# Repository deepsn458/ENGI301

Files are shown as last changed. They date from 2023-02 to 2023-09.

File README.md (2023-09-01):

# ENGI301
This is a repository for my ENGI301 (Introduction to Practical Electrical Engineering) coursework

The main project is a two-player pattern guesser game made using the Pocket Beagle microprocessor.

[project_01](https://github.com/deepsn458/ENGI301/tree/main/project_01) contains the python code used to run the game

[project_02](https://github.com/deepsn458/ENGI301/tree/main/project_02) contains the schematics and board files for the PCB that was designed for the game

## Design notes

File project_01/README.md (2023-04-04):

# 2 Player Pattern Memory Game

## Introduction
This repository provides the code needed to run the Pattern Memory Game on the PocketBeagle. For more information on the game and setting up the hardware, please visit the [hackster.io](https://www.hackster.io/deepaknarayan458/pattern-guesser-bdb78b) page.

## Dependencies
* Python Package Manager (PIP)
* Adafruit BBIO library
* Adafruit Trellis Library

### Follow the instructions below to install these dependencies
Run the following shell commands in your terminal window
* Update the Linux Advanced Package Tool (apt) and install the Build-Essential package
```sh
  sudo apt-get update
  sudo apt-get install build-essential python-dev python setuptools python-smbus -y
 ```
 * Installing pip
 Install the version compatible with your version of python (version 2.x.x vs version 3.x.x)
 ```sh
 sudo apt-get install python-pip -y
 sudo apt-get install python3-pip -y
 ```
 * Install zip
 ```sh
 sudo apt-get install zip
 ```
* Install the required Adafruit libraries
```sh
sudo pip3 install --upgrade setuptools
sudo pip3 install --upgrade Adafruit_BBIO
sudo pip3 install adafruit-blinka
sudo pip3 install adafruit-circuitpython-trellis
```

## Usage
The game will run when the PocketBeagle is powered on. It can also be run from the Cloud9 IDE with the following commands
```sh
debian@beaglebone:/var/lib/cloud9/ENGI301/project_01/main_game$ ./run
```
### Testing hardware drivers
Navigate to the drivers directory to access the python files for the hardware drivers.
The following command will run the button driver test
```sh
debian@beaglebone:/var/lib/cloud9/ENGI301/project_01/drivers$ python3 nav_button.py
```

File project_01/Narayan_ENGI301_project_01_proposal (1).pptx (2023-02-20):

## ENGI 301 2- Player Pattern Memory Game Proposal

13th February 2023
Deepak Narayan

## Background Information: My Story

- One player sets a pattern using a keypad; the other is briefly shown the pattern and then attempts to replicate it correctly
- Turning the standard memory pattern game into a 2-player game seemed like a good project to get started in learning to make a game
- I am also interested in learning about multiplexing and Charlieplexing. I hope to learn a lot about how LED matrices work through this project.

## Background Information: Overview of the Game

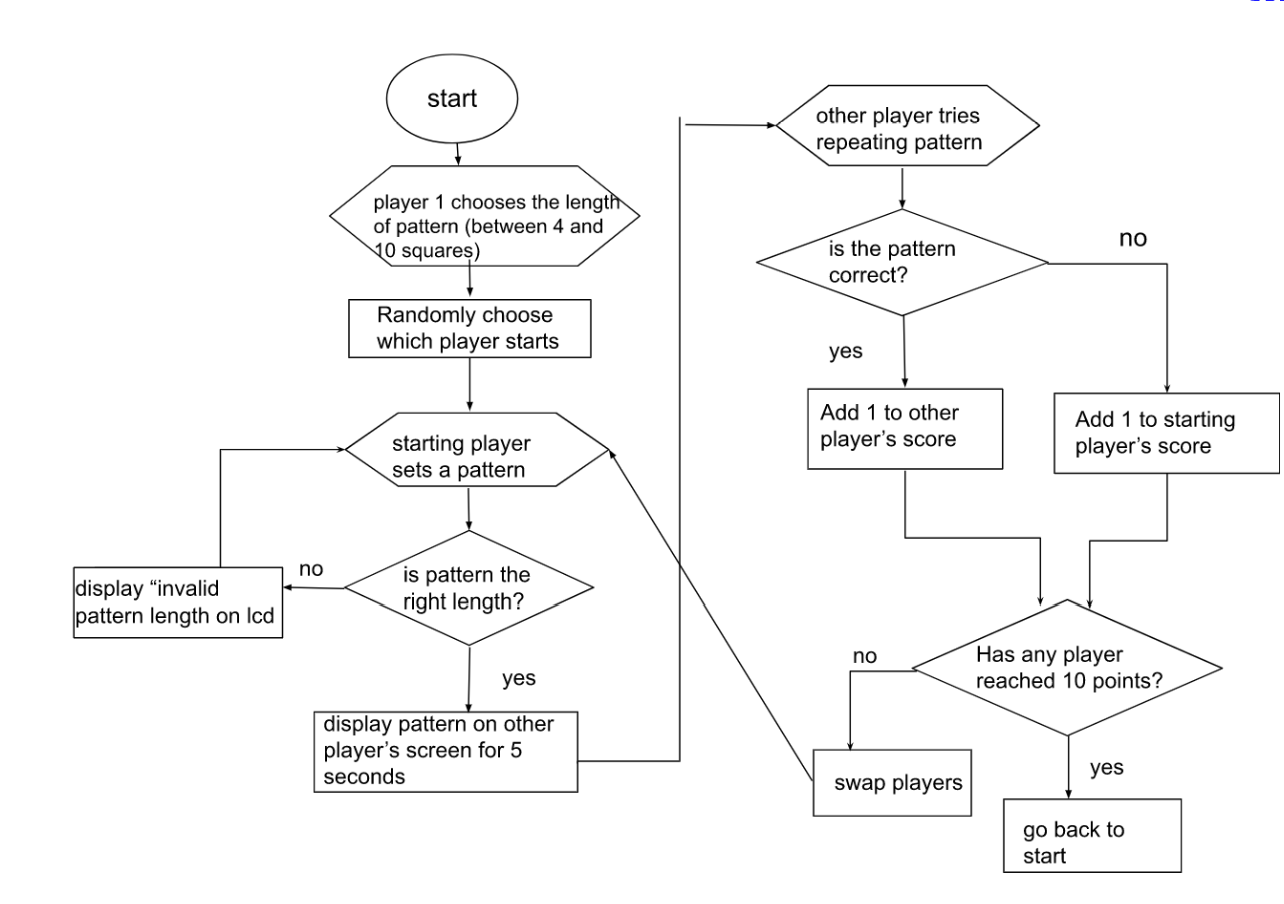
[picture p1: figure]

Figure 1: Game Logic Flowchart

## Background Information: The Device

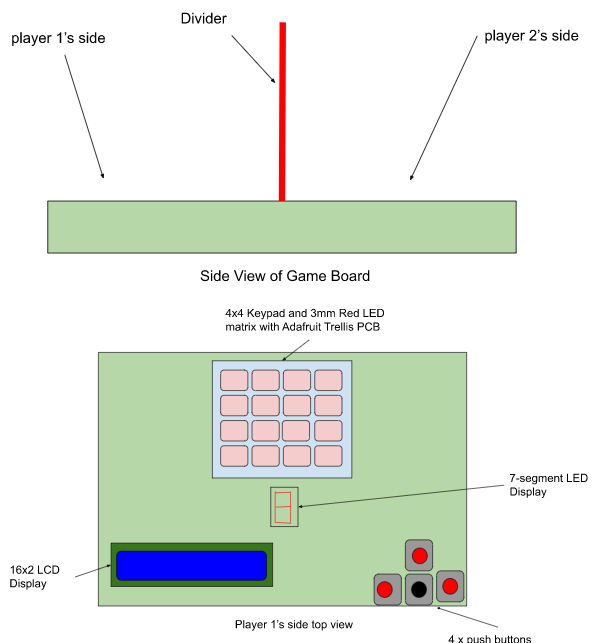
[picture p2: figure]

Figure 2: Side view of game board (top) and top view of Player 1’s side(bottom)

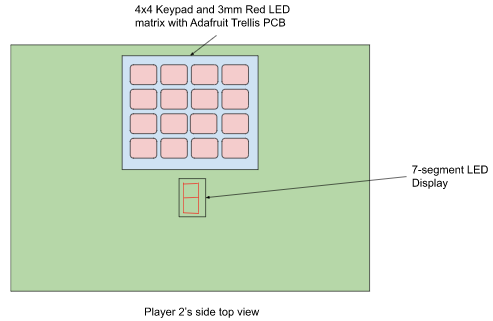
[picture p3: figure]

Figure 3: Top view of player 2’s side

## Background Information: The Device

- Player 1 interfaces with LCD with the pushbuttons to select the pattern length
- Players’ Score is shown on 7-segment LED

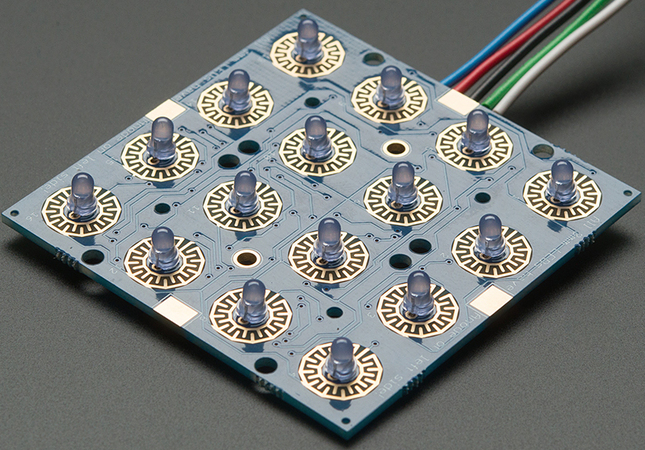
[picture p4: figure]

Figure 4: Adafruit Trellis PCB with LEDs installed (Rembor) [1]

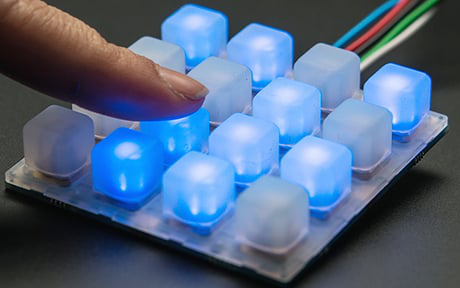
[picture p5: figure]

Figure 5: Adafruit Trellis PCB with LEDs and 4x4 keypad (Rembor) [2]

[1]: Rembor, Kattni “Adding LEDs” Adafruit, 6 Dec. 2013, https://learn.adafruit.com/adafruit-trellis-diy-open-source-led-keypad/adding-leds Accessed 12 Feb. 2023.

[2]: Rembor, Kattni “Overview” Adafruit, 6 Dec. 2013, https://learn.adafruit.com/adafruit-trellis-diy-open-source-led-keypad/overview Accessed 12 Feb. 2023

## Background Information: Existing Project and Improvements

- My project is based on a Pattern Memory Game with the Tessel 1 Development Board:
  - https://www.hackster.io/nmoadev/rebloc-099bdd
  - https://github.com/nmoadev/reBloc/blob/master/rebloc.js
  - My project adds multiplayer and the option to choose the size of the pattern.
    - Additional software: code to store patterns, validate patterns, swap players, and count score
    - Additional hardware: 16x2 LCD display, push buttons, 7-segment LED Display

## System Block Diagram

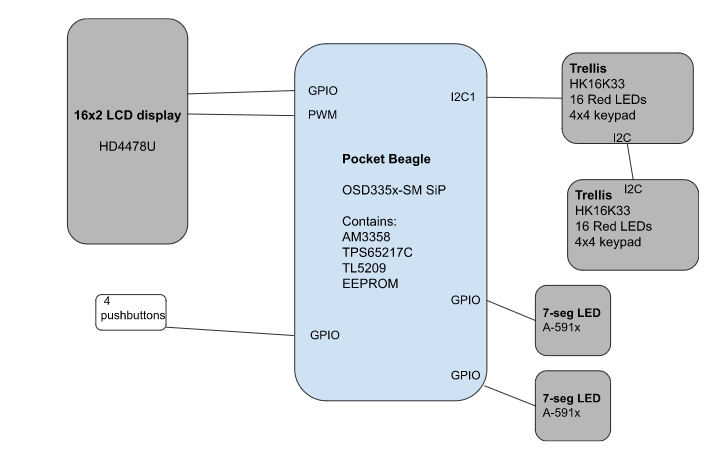
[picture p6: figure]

Figure 5: System block diagram for the game

## Power Block Diagram

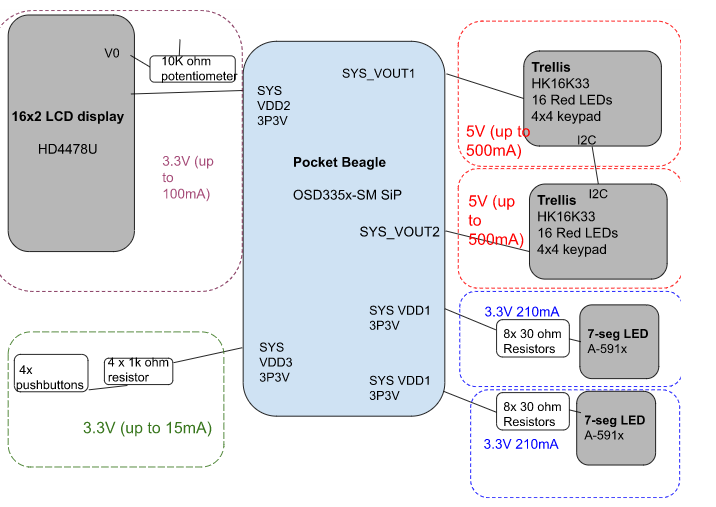
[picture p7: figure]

The datasheet for the Trellis does not specify an exact value for the current draw. An additional power source might be needed.

Figure 6: Power Block Diagram of Game

## Components / Budget

Component | Need to Buy | Total
Adafruit Trellis Driver PCB (https://www.adafruit.com/product/1616) | 2 | $19.90
Trellis Elastomer Keypad (https://www.digikey.com/en/products/detail/adafruit-industries-llc/1611/5823361) | 2 | $9.90
Standard LCD 16x2 + extras (https://www.adafruit.com/product/181https:/www.adafruit.com/product/181) | 1 | $9.95
USB power supply (https://www.amazon.com/SIXTHGU-Portable-Capacity-External-Indicator/dp/B08QHG7BTB) | 1 | $11.89
7-Segment LED Display (https://www.adafruit.com/product/1002) | 1 | $10.95

I can source the 7-seg LEDs, buttons, and Red LEDs myself and from the parts kit

An additional power source may be needed after the current draw of the Trellis is measured

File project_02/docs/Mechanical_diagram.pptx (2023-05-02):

## ENGI 301 PCB Project

Deepak Narayan
Due 05/02/2022 @ 11:59pm

## Options

- Can choose one of two options:
  1. Create a PCB based on your Project #1
  2. Create a PCB based on an example project
- See Project #2 assignment for specific details
  - If choosing Option 1
    - Replace Background Information and System Block Diagram slides with your slides from the Project #1 proposal
    - Create a Mechanical Drawing
  - If choosing Option 2
    - Used provided Background Information and System Block Diagram slides
    - Create a Mechanical Drawing

## Background Information: The Device

- Player 1 interfaces with LCD with the pushbuttons to select the pattern length
- Players’ Score is shown on 7-segment LED


Figure 4: Adafruit Trellis PCB with LEDs installed (Rembor) [1]


Figure 5: Adafruit Trellis PCB with LEDs and 4x4 keypad (Rembor) [2]

[1]: Rembor, Kattni “Adding LEDs” Adafruit, 6 Dec. 2013, https://learn.adafruit.com/adafruit-trellis-diy-open-source-led-keypad/adding-leds Accessed 12 Feb. 2023.

[2]: Rembor, Kattni “Overview” Adafruit, 6 Dec. 2013, https://learn.adafruit.com/adafruit-trellis-diy-open-source-led-keypad/overview Accessed 12 Feb. 2023

## Background Information: Existing Project and Improvements

- My project is based on a Pattern Memory Game with the Tessel 1 Development Board:
  - https://www.hackster.io/nmoadev/rebloc-099bdd
  - https://github.com/nmoadev/reBloc/blob/master/rebloc.js
  - My project adds multiplayer and the option to choose the size of the pattern.
    - Additional software: code to store patterns, validate patterns, swap players, and count score
    - Additional hardware: 16x2 LCD display, push buttons, 7-segment LED Display

## System Block Diagram

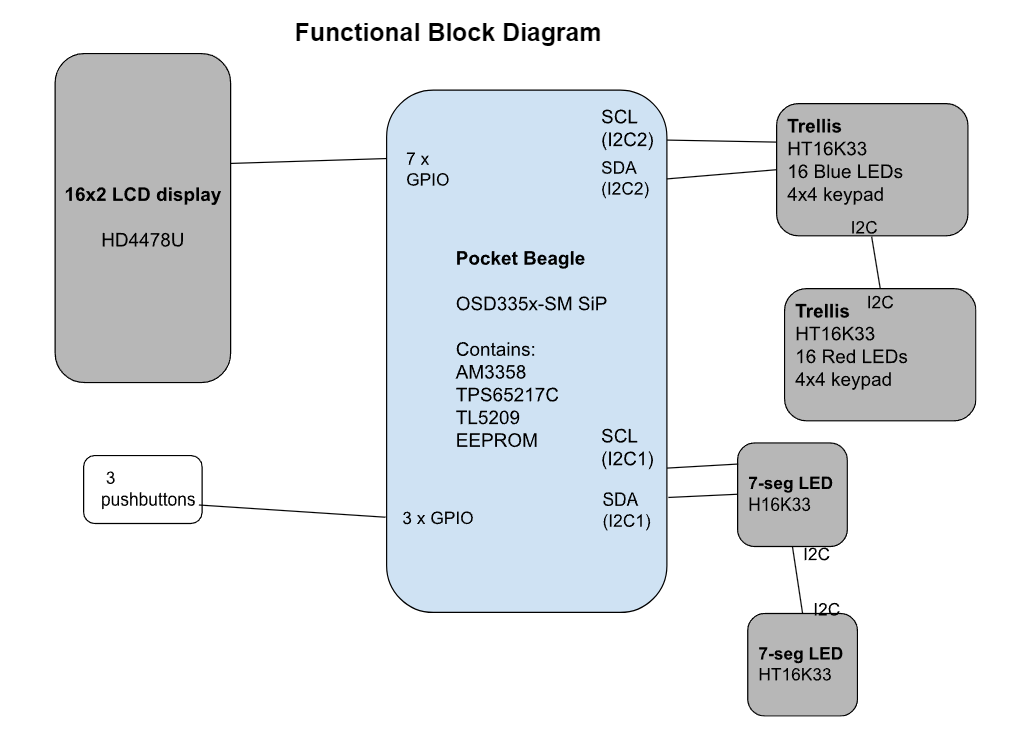
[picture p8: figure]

Figure 5: System block diagram for the game

## Mechanical Drawing

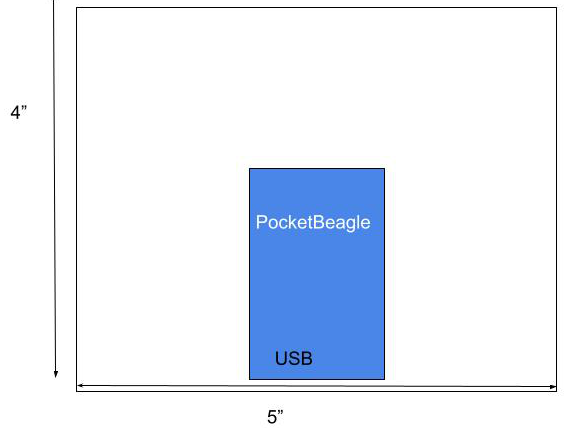
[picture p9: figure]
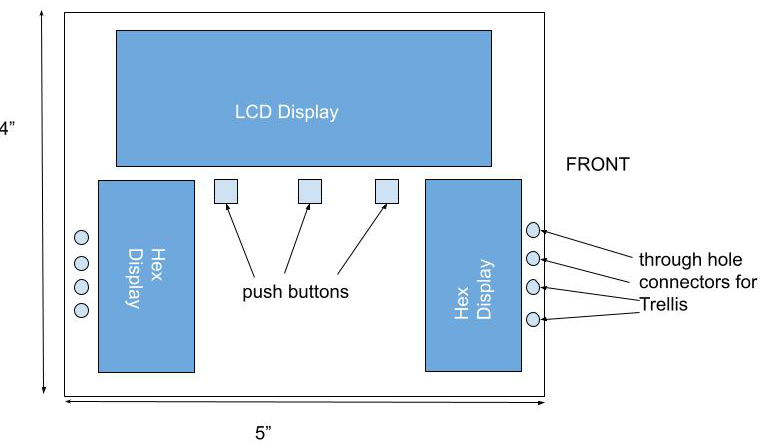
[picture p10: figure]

FRONT

BACK

## Example Mechanical Drawing (from Combo Lock)

Hex Display

3”

.25”

Pocket Beagle

.5”

USB

2”

Button

Pot

Buzzer

Servo

1.5”

FRONT

BACK

Remove this slide in your submission

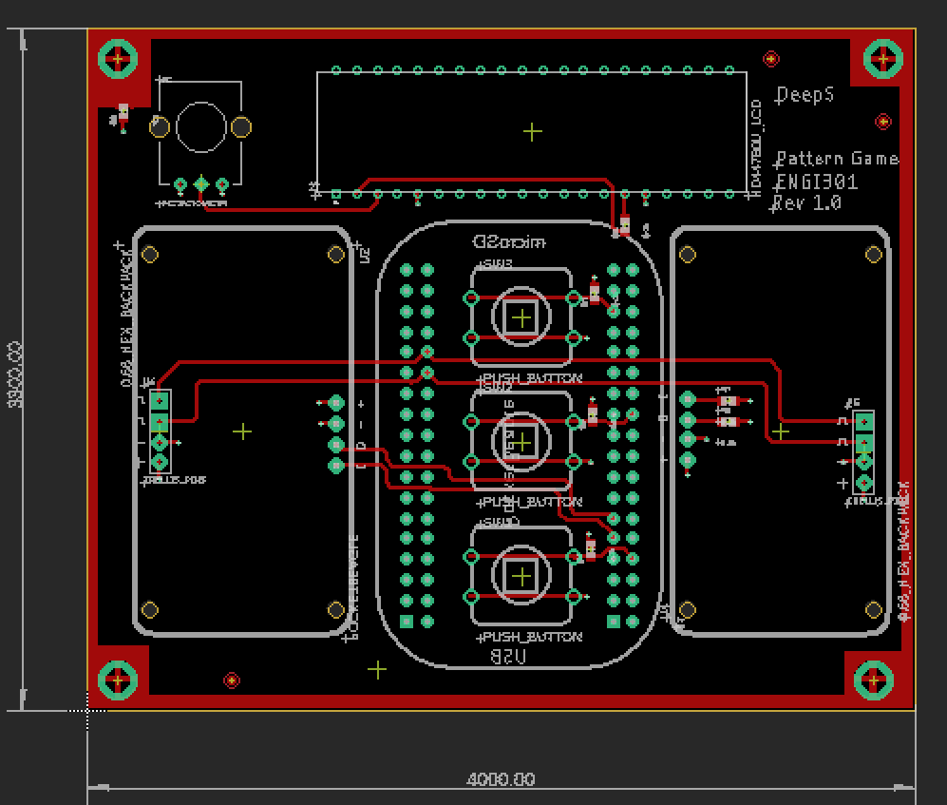
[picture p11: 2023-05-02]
project_02/docs/Top_Layer.png

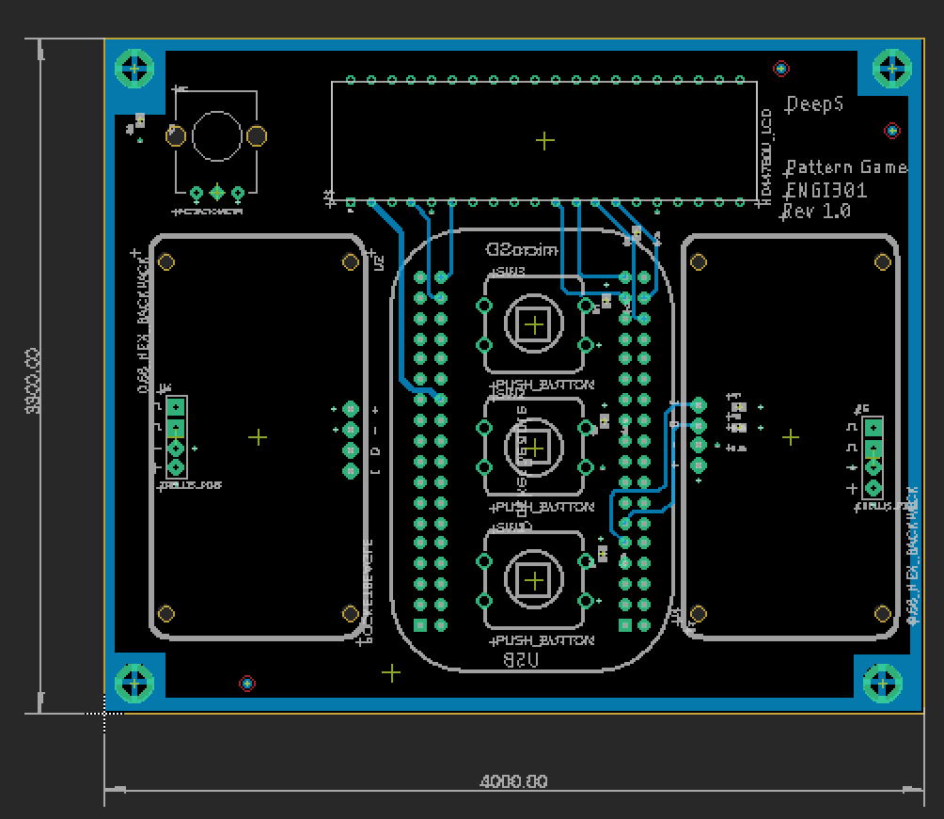
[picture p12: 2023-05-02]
project_02/docs/Bottom_Layer.png

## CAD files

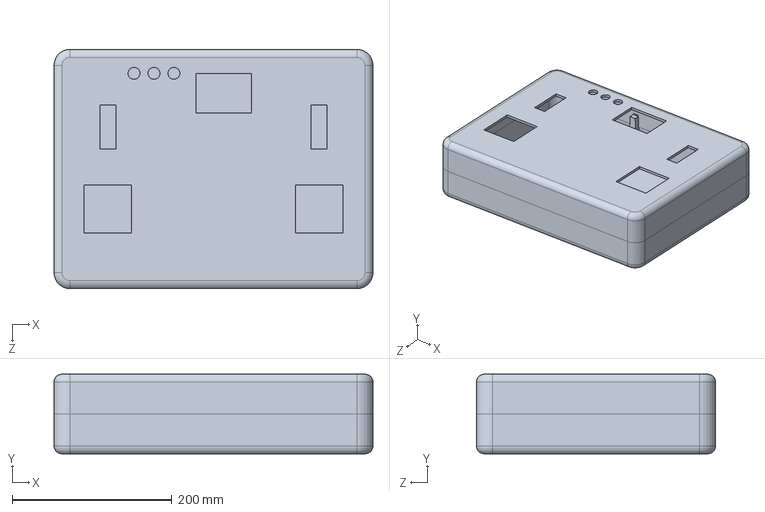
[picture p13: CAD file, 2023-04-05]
enclosure.SLDPRT
400.0 x 100.0 x 300.0 mm

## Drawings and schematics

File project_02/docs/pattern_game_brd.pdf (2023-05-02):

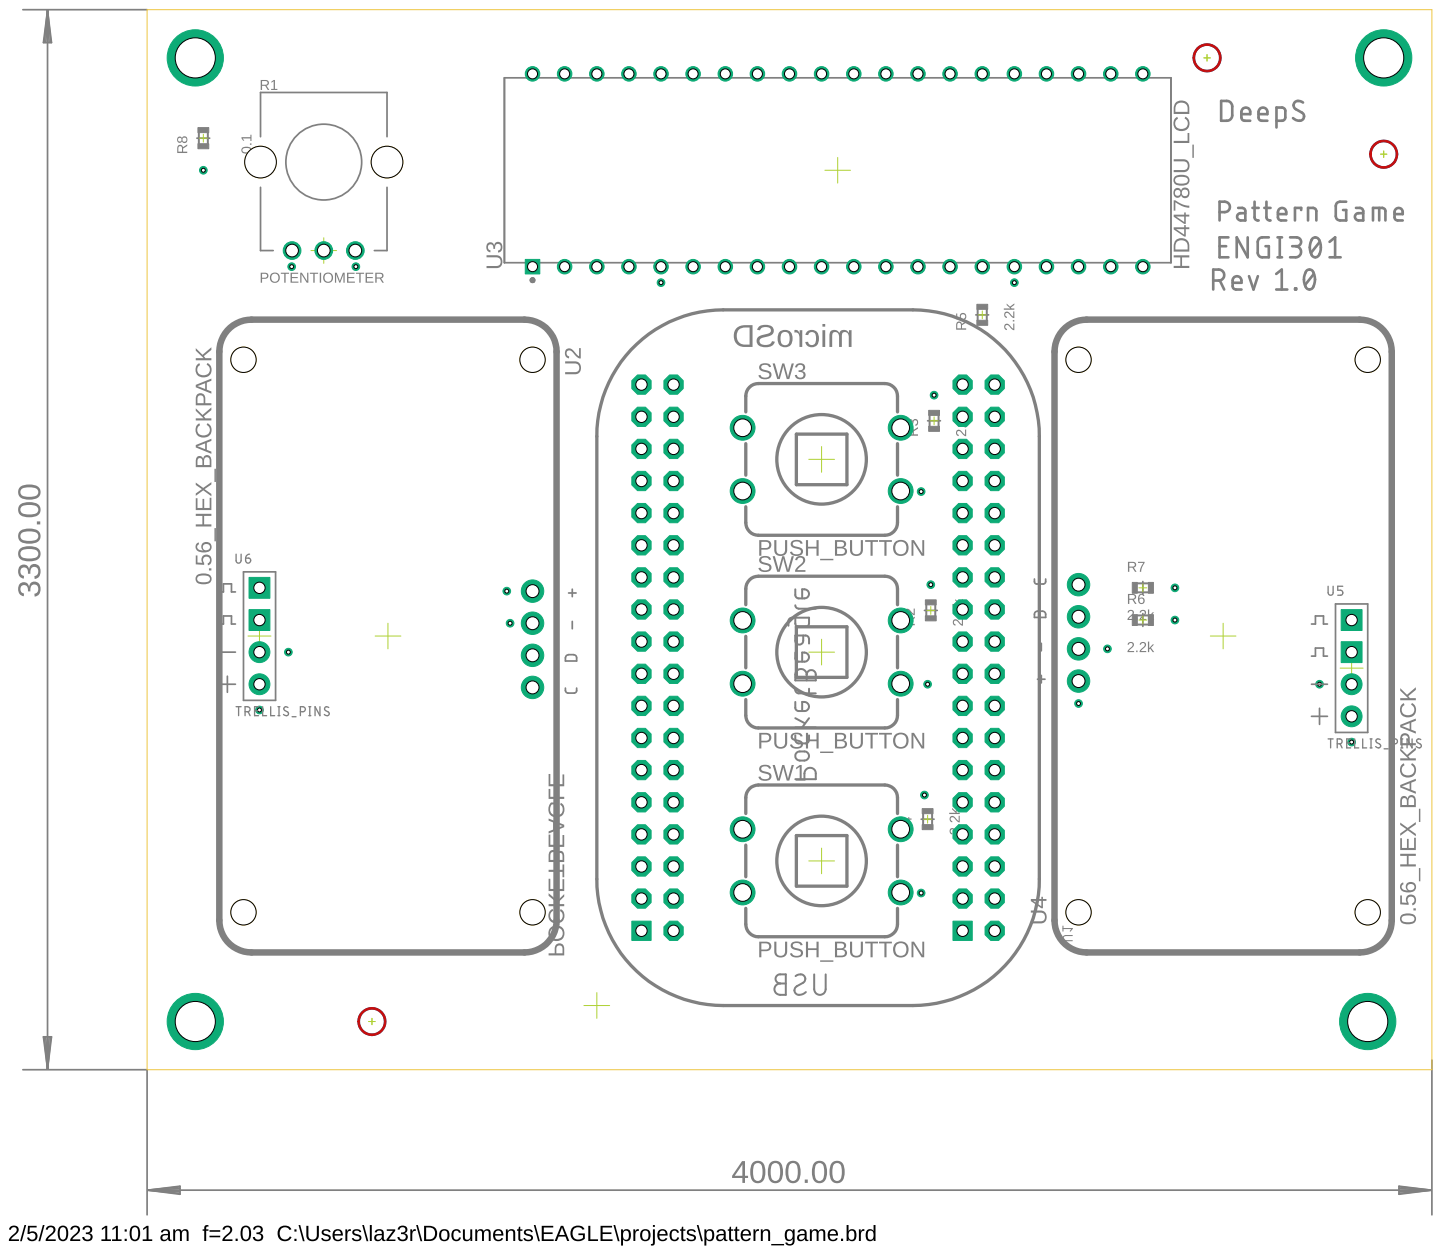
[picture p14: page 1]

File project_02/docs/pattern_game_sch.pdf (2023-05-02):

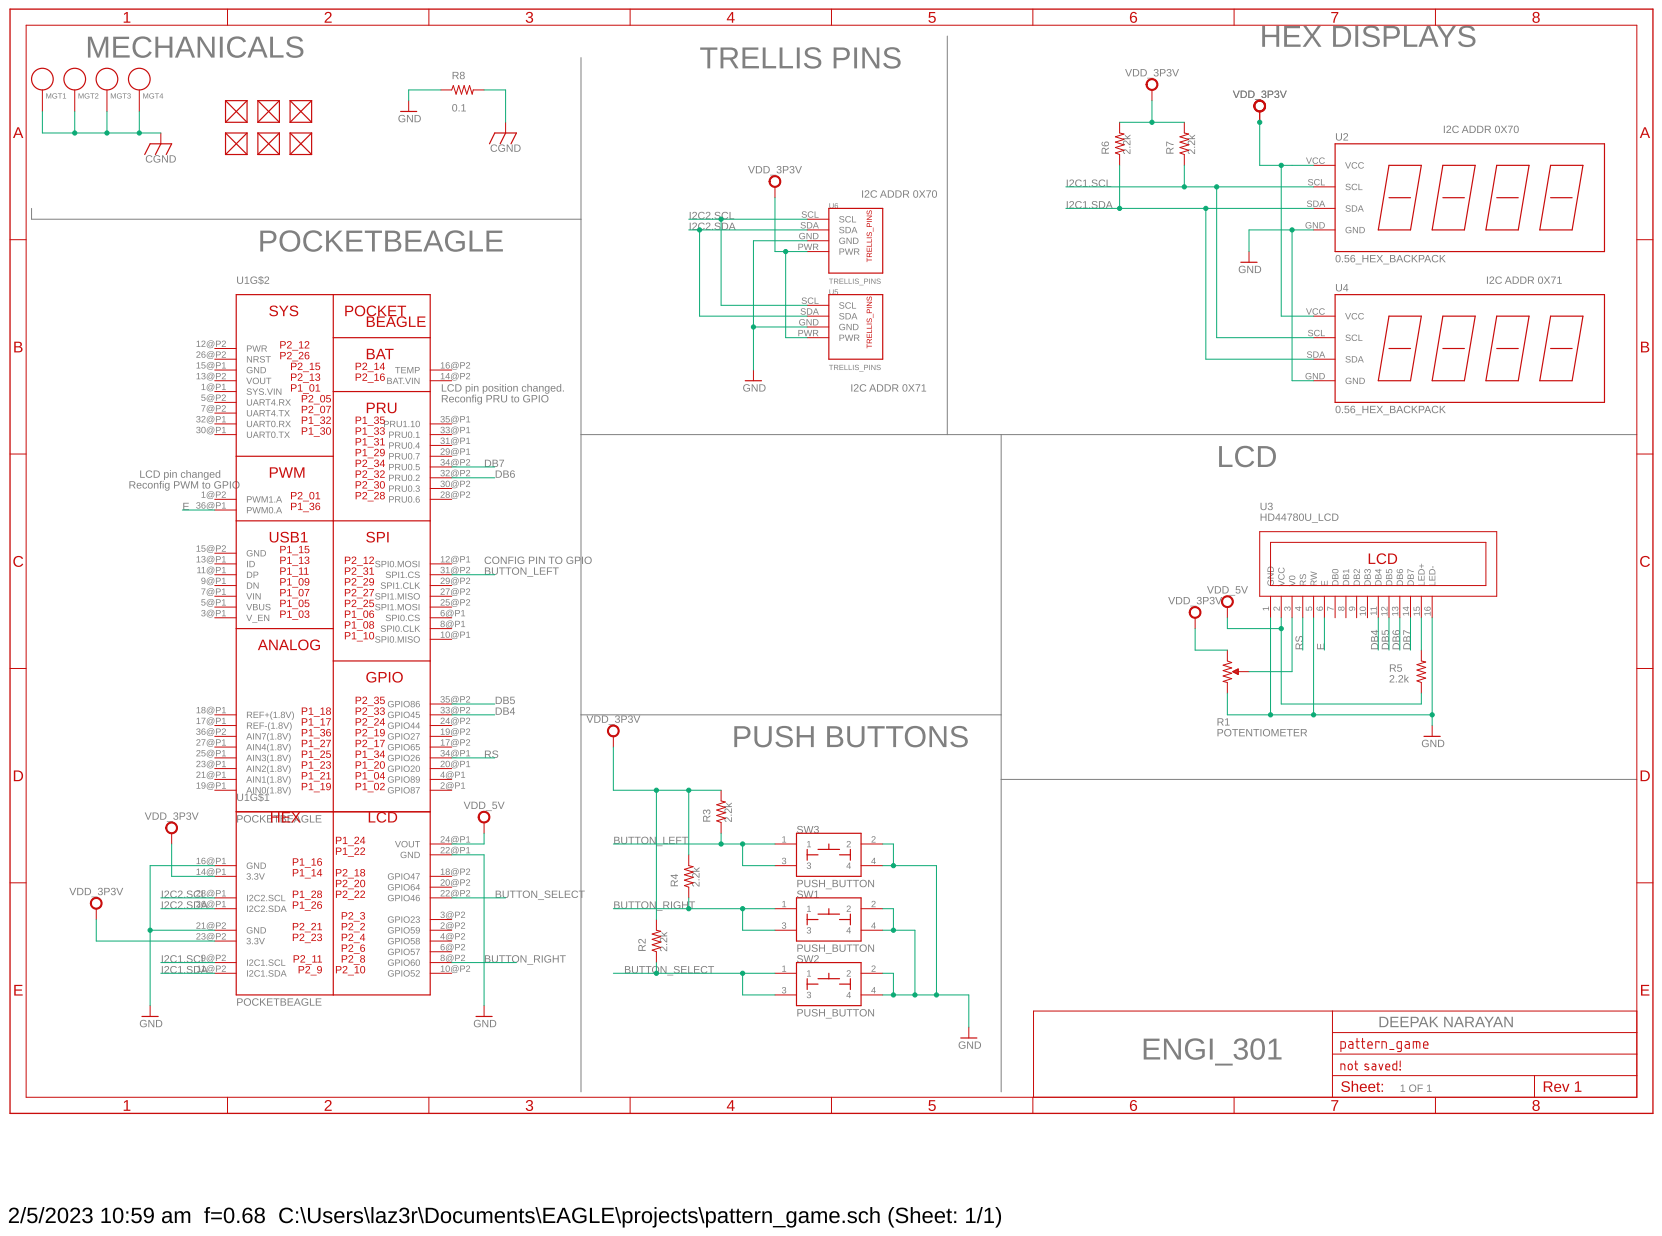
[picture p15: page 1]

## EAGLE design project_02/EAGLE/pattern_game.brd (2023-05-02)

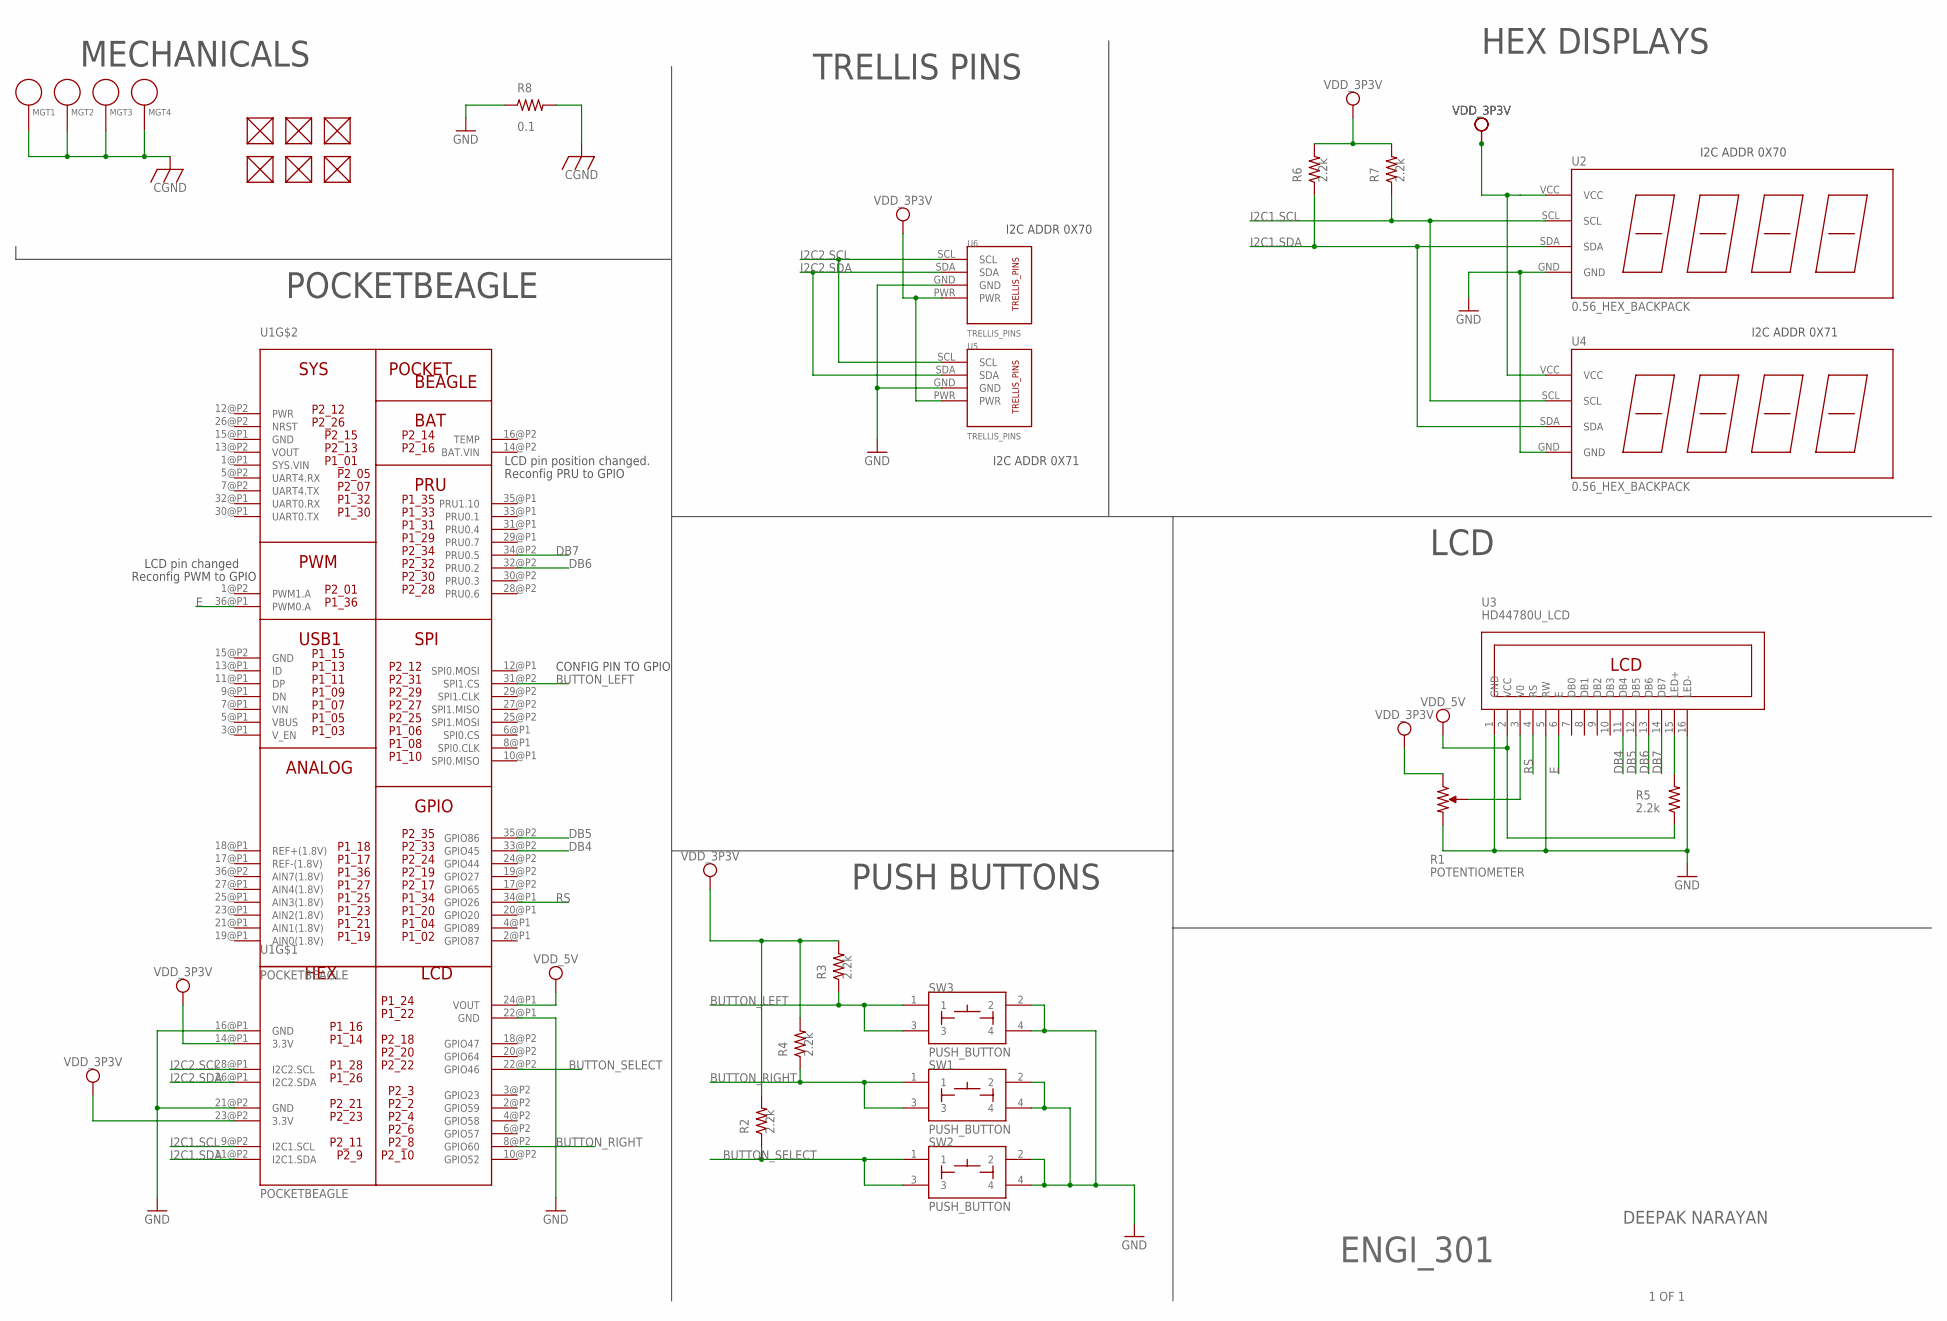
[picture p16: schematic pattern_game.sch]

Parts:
FUD1, FUD2, FUD3, FUD4, FUD5, FUD6: FIDUCIAL; FIDUCIAL_40MIL
MGT1, MGT2, MGT3, MGT4: MOUNTING_HOLE
R1: POTENTIOMETER; POT-PO90S
R2, R3, R4, R5, R6, R7: 2.2k; R0603
R8: 0.1; R0603
SW1, SW2, SW3: PUSH_BUTTON; BUTTON_12.5MM
U1: POCKETBEAGLE
U2, U4: 0.56_HEX_BACKPACK
U3: HD44780U_LCD
U5, U6: TRELLIS_PINS

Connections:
BUTTON_LEFT: R3.1, SW3.1, SW3.3, U1.31@P2 (SPI1.CS)
BUTTON_RIGHT: R4.1, SW1.1, SW1.3, U1.8@P2 (GPIO60)
BUTTON_SELECT: R2.1, SW2.1, SW2.3, U1.22@P2 (GPIO46)
CGND: MGT1.P$1, MGT2.P$1, MGT3.P$1, MGT4.P$1, R8.2
DB4: U1.33@P2 (GPIO45), U3.11 (DB4)
DB5: U1.35@P2 (GPIO86), U3.12 (DB5)
DB6: U1.32@P2 (PRU0.2), U3.13 (DB6)
DB7: U1.34@P2 (PRU0.5), U3.14 (DB7)
E: U1.36@P1 (PWM0.A), U3.6 (E)
GND: R1.CW, R8.1, SW1.2, SW1.4, SW2.2, SW2.4, SW3.2, SW3.4, U1.16@P1 (GND), U1.21@P2 (GND), U1.22@P1 (GND), U2.GND, U3.1 (GND), U3.5 (RW), U3.16 (LED-), U4.GND, U5.GND, U6.GND
I2C1.SCL: R7.1, U1.9@P2 (I2C1.SCL), U2.SCL, U4.SCL
I2C1.SDA: R6.1, U1.11@P2 (I2C1.SDA), U2.SDA, U4.SDA
I2C2.SCL: U1.28@P1 (I2C2.SCL), U5.SCL, U6.SCL
I2C2.SDA: U1.26@P1 (I2C2.SDA), U5.SDA, U6.SDA
unnamed: R1.S, U3.3 (V0)
unnamed: R5.2, U3.15 (LED+)
RS: U1.34@P1 (GPIO26), U3.4 (RS)
VDD_3P3V: R1.CCW, R2.2, R3.2, R4.2, R6.2, R7.2, U1.14@P1 (3.3V), U1.23@P2 (3.3V), U2.VCC, U4.VCC, U5.PWR, U6.PWR
VDD_5V: R5.1, U1.24@P1 (VOUT), U3.2 (VCC)

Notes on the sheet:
LCD
HEX DISPLAYS
I2C ADDR 0X70
I2C ADDR 0X71
TRELLIS PINS
POCKETBEAGLE
PUSH BUTTONS
MECHANICALS
ENGI_301
DEEPAK NARAYAN
1 OF 1
LCD pin position changed.
Reconfig PRU to GPIO
LCD pin changed
Reconfig PWM to GPIO
CONFIG PIN TO GPIO

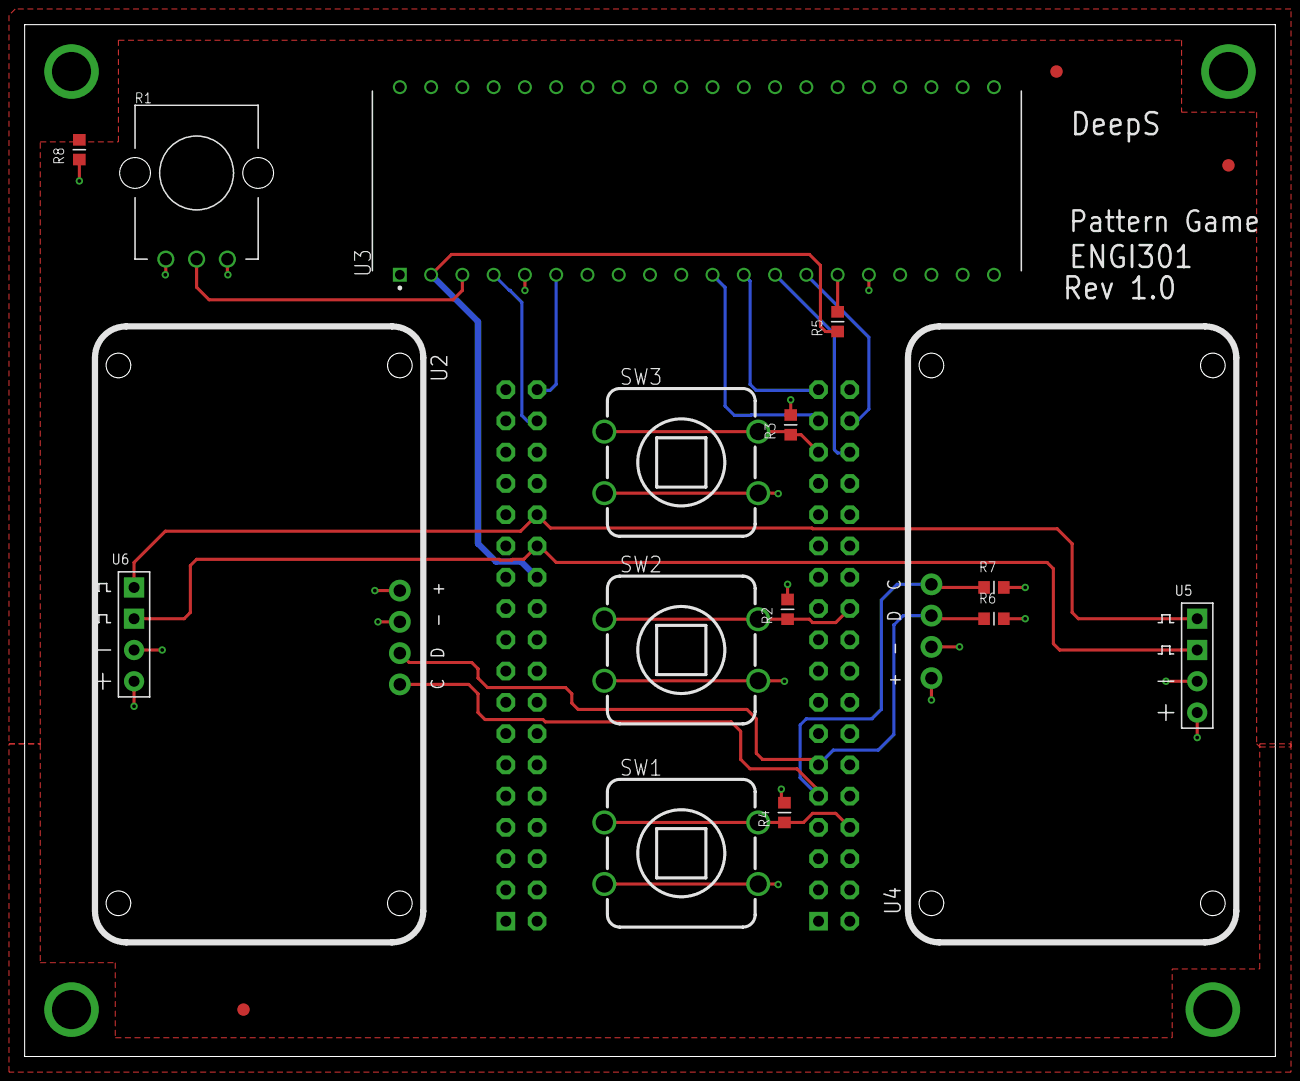
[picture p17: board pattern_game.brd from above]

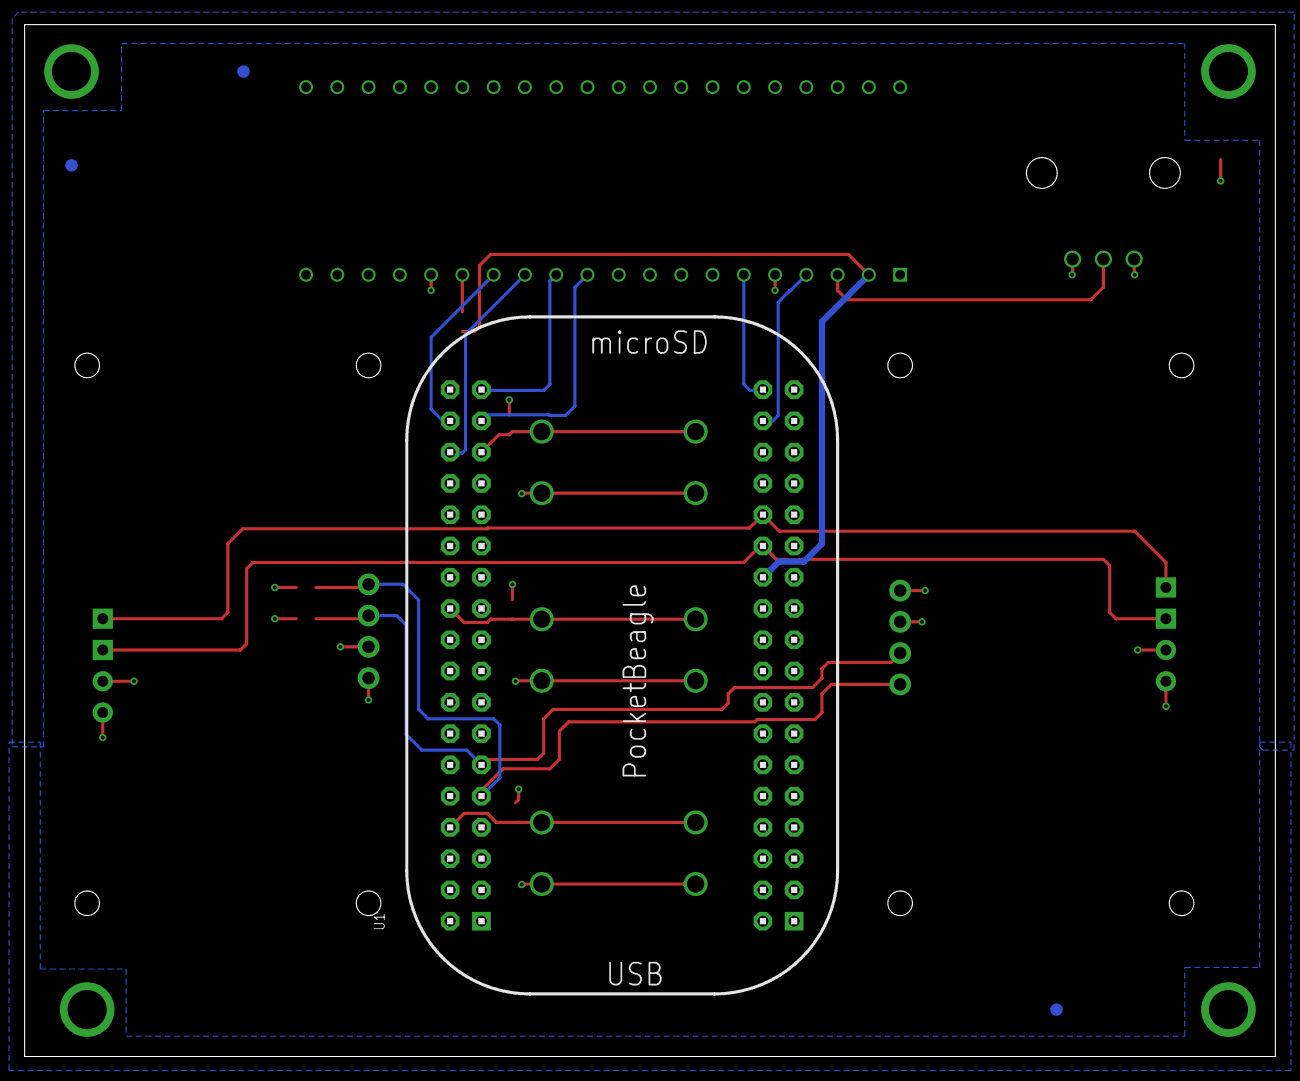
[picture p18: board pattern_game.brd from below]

Board: 4 copper layers, 101.6 x 83.8 mm, 27 parts (4 on the bottom side), 19 nets.

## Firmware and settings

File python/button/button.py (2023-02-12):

"""
--------------------------------------------------------------------------
Button Driver
--------------------------------------------------------------------------
License:   
Copyright 2021-2023 - Erik Welsh

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
1. Redistributions of source code must retain the above copyright notice, this 
list of conditions and the following disclaimer.

2. Redistributions in binary form must reproduce the above copyright notice, 
this list of conditions and the following disclaimer in the documentation 
and/or other materials provided with the distribution.

3. Neither the name of the copyright holder nor the names of its contributors 
may be used to endorse or promote products derived from this software without 
specific prior written permission.

THIS SOFTWARE IS PROVIDED BY THE COPYRIGHT HOLDERS AND CONTRIBUTORS "AS IS" 
AND ANY EXPRESS OR IMPLIED WARRANTIES, INCLUDING, BUT NOT LIMITED TO, THE 
IMPLIED WARRANTIES OF MERCHANTABILITY AND FITNESS FOR A PARTICULAR PURPOSE ARE 
DISCLAIMED. IN NO EVENT SHALL THE COPYRIGHT HOLDER OR CONTRIBUTORS BE LIABLE 
FOR ANY DIRECT, INDIRECT, INCIDENTAL, SPECIAL, EXEMPLARY, OR CONSEQUENTIAL 
DAMAGES (INCLUDING, BUT NOT LIMITED TO, PROCUREMENT OF SUBSTITUTE GOODS OR 
SERVICES; LOSS OF USE, DATA, OR PROFITS; OR BUSINESS INTERRUPTION) HOWEVER 
CAUSED AND ON ANY THEORY OF LIABILITY, WHETHER IN CONTRACT, STRICT LIABILITY, 
OR TORT (INCLUDING NEGLIGENCE OR OTHERWISE) ARISING IN ANY WAY OUT OF THE USE 
OF THIS SOFTWARE, EVEN IF ADVISED OF THE POSSIBILITY OF SUCH DAMAGE.
--------------------------------------------------------------------------

Button Driver

  This driver is built for buttons that have a pull up resistor between the
button and the processor pin (i.e. the input is "High"/"1" when the button is
not pressed) and will be connected to ground when the button is pressed (i.e. 
the input is "Low" / "0" when the button is pressed)

Software API:

  Button(pin)
    - Provide pin that the button monitors
    
    is_pressed()
      - Return a boolean value (i.e. True/False) on if button is pressed
      - Function consumes no time
    
    wait_for_press(function=None)
      - Wait for the button to be pressed 
      - Optionally takes in an argument "function" which is the function 
        to be executed when waiting for the button to be pressed
      - Function consumes time
      - Returns a tuple:  
        (<time button was pressed>, <data returned by the "function" argument>)

"""
import time

import Adafruit_BBIO.GPIO as GPIO

# ------------------------------------------------------------------------
# Constants
# ------------------------------------------------------------------------

# None

# ------------------------------------------------------------------------
# Global variables
# ------------------------------------------------------------------------

# None

# ------------------------------------------------------------------------
# Functions / Classes
# ------------------------------------------------------------------------

class Button():
    """ Button Class """
    pin             = None
    unpressed_value = None
    pressed_value   = None
    sleep_time      = None
    
    def __init__(self, pin=None):
        """ Initialize variables and set up the button """
        if (pin == None):
            raise ValueError("Pin not provided for Button()")
        else:
            self.pin = pin
        
        # By default the unpressed_value is "1" and the pressed
        # value is "0".  This is done to make it easier to change
        # in the future
        self.unpressed_value = 1
        self.pressed_value   = 0
        
        # By default sleep time is "0.1" seconds
        self.sleep_time      = 0.1

        # Initialize the hardware components        
        self._setup()
    
    # End def
    
    
    def _setup(self):
        """ Setup the hardware components. """
        # Initialize Button
        # HW#4 TODO: (one line of code)
        #   Remove "pass" and use the Adafruit_BBIO.GPIO library to set up the button
        GPIO.setup(self.pin, GPIO.IN)
        return
    # End def


    def is_pressed(self):
        """ Is the Button pressed?
        
           Returns:  True  - Button is pressed
                     False - Button is not pressed
        """
        # HW#4 TODO: (one line of code)
        #   Remove "pass" and return the comparison of input value of the GPIO pin of 
        #   the buton (i.e. self.pin) to the "pressed value" of the class 
        print(GPIO.input(self.pin))
        return (GPIO.input(self.pin) == self.pressed_value)

    # End def


    def wait_for_press(self, function=None):
        """ Wait for the button to be pressed.  This function will 
           wait for the button to be pressed and released so there
           are no race conditions.
        
           Arguments:
               function - Optional argument that is the functon to 
                          executed while waiting for the button to 
                          be pressed
        
           Returns:
               tuple - [0] Time button was pressed
                     - [1] Data returned by the "function" argument
        """
        function_return_value = None
        button_press_time     = None
        
        # Execute function if it is not None
        #   - This covers the case that the button is pressed prior 
        #     to entering this function
        if function is not None:
            function_return_value = function()
        
        # Wait for button press
        #   If the function is not None, execute the function
        #   Sleep for a short amount of time to reduce the CPU load
        #
        # HW#4 TODO: (one line of code)
        #   Update while loop condition to compare the input value of the  
        #   GPIO pin of the buton (i.e. self.pin) to the "unpressed value" 
        #   of the class (i.e. we are executing the while loop while the 
        #   button is not being pressed)
        while(GPIO.input(self.pin) == self.unpressed_value):
            if function is not None:
                function_return_value = function()
                
            time.sleep(self.sleep_time)
        
        # Record time
        button_press_time = time.time()
        
        # Wait for button release
        #   Sleep for a short amount of time to reduce the CPU load
        #
        # HW#4 TODO: (one line of code)
        #   Update while loop condition to compare the input value of the  
        #   GPIO pin of the buton (i.e. self.pin) to the "pressed value" 
        #   of the class (i.e. we are executing the while loop while the 
        #   button is being pressed)
        while(GPIO.input(self.pin) == self.pressed_value):
            time.sleep(self.sleep_time)
        
        # Compute the button_press_time
        button_press_time = time.time() - button_press_time

        # Return a tuple:  (button press time, function return value)        
        return (button_press_time, function_return_value)
        
    # End def

# End class



# ------------------------------------------------------------------------
# Main script
# ------------------------------------------------------------------------

if __name__ == '__main__':

    print("Button Test")

    # Create instantiation of the button
    button = Button("P2_2")
    
    # Create an function to test the wait_for_press function
    def print_time():
        ret_val = time.time()
        print("    Print Time = {0}".format(ret_val))
        return ret_val
    # End def

    # Use a Keyboard Interrupt (i.e. "Ctrl-C") to exit the test
    try:
        # Check if the button is pressed
        print("Is the button pressed?")
        print("    {0}".format(button.is_pressed()))

        print("Press and hold the button.")
        time.sleep(4)
        
        # Check if the button is pressed
        print("Is the button pressed?")
        print("    {0}".format(button.is_pressed()))
        
        print("Release the button.")
        time.sleep(4)
        
        print("Waiting for button press ...")
        value = button.wait_for_press()
        print("    Button pressed for {0} seconds. ".format(value[0]))
        print("    Function return value = {0}".format(value[1]))
        
        print("Waiting for button press with optional argument ...")
        value = button.wait_for_press(print_time)
        print("    Button pressed for {0} seconds. ".format(value[0]))
        print("    Function return value = {0}".format(value[1]))
        
    except KeyboardInterrupt:
        pass

    print("Test Complete")

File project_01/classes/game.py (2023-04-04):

"""
--------------------------------------------------------------------------
Game class
--------------------------------------------------------------------------
License:   
Copyright 2021-2023 Deepak Narayan

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
1. Redistributions of source code must retain the above copyright notice, this 
list of conditions and the following disclaimer.

2. Redistributions in binary form must reproduce the above copyright notice, 
this list of conditions and the following disclaimer in the documentation 
and/or other materials provided with the distribution.

3. Neither the name of the copyright holder nor the names of its contributors 
may be used to endorse or promote products derived from this software without 
specific prior written permission.

THIS SOFTWARE IS PROVIDED BY THE COPYRIGHT HOLDERS AND CONTRIBUTORS "AS IS" 
AND ANY EXPRESS OR IMPLIED WARRANTIES, INCLUDING, BUT NOT LIMITED TO, THE 
IMPLIED WARRANTIES OF MERCHANTABILITY AND FITNESS FOR A PARTICULAR PURPOSE ARE 
DISCLAIMED. IN NO EVENT SHALL THE COPYRIGHT HOLDER OR CONTRIBUTORS BE LIABLE 
FOR ANY DIRECT, INDIRECT, INCIDENTAL, SPECIAL, EXEMPLARY, OR CONSEQUENTIAL 
DAMAGES (INCLUDING, BUT NOT LIMITED TO, PROCUREMENT OF SUBSTITUTE GOODS OR 
SERVICES; LOSS OF USE, DATA, OR PROFITS; OR BUSINESS INTERRUPTION) HOWEVER 
CAUSED AND ON ANY THEORY OF LIABILITY, WHETHER IN CONTRACT, STRICT LIABILITY, 
OR TORT (INCLUDING NEGLIGENCE OR OTHERWISE) ARISING IN ANY WAY OUT OF THE USE 
OF THIS SOFTWARE, EVEN IF ADVISED OF THE POSSIBILITY OF SUCH DAMAGE.
--------------------------------------------------------------------------
The game super class provides the methods that are common between the one player game mode and the two player game mode

APIs:
    - Game()
        - setPatternSize() DONE
            - Sets the number of presses for each pattern
            
        - checkPress(location, pattern_list, press_counter) DONE
            - Checks if the guesser pressed the correct key
            - location is the key pressed
            - pattern_list represents the pattern set by the setter
            - press_counter is the current step in the pattern
        
        - checkWinner(p1_score, p2_score) DONE
            - checks if any player/cpu has reached 10 points
            - p1_score is the score of player 1
            - p2_score is the score of player 2 or the cpu
        
        - guessPattern(guesser, pattern_size, pattern_list) DONE
            - checks if the guesser guessed the whole pattern correctly
            - guesser is an instance of the Guesser class
            - pattern_list is the pattern set by the setter
            - pattern_size is the length of pattern_list
        
        - OnePlayer(Game)
            - pins for led, buttons, trellis, lcd are passed as input
            - setup()
                - sets up the hardware for the one player game mode
            
            - run()
                - runs the one player game mode
            
            - playOnePlayer(pattern_length)
                - runs the actual game for the one player mode
                - pattern_length is the length of pattern_list
            
            -cleanup()
                - returns all hardware to default state
        
        
        -TwoPlayer(Game)
            - - pins for led, buttons, trellis, lcd are passed as input
            - setup()
                - sets up the hardware for the two player game mode
            
            - run()
                - runs the two player game mode
            
            - playTwoPlayer(pattern_length)
                - runs the actual game for the two player mode
                - pattern_length is the length of pattern_list
            
            - chooseGuesser(trellis1, trellis2, led1, led2)
                - randomely chooses which player will be the guesser and which will be the setter
                - trellis 1 and 2 are the keypad/led matrices for player 1 and 2 respectives
                - led1 and 2 are the led displays for player 1 and 2 respectively
            
            - swap(guesser, setter)
                - swaps the guesser and setter after each game
    --------------------------------------------------------------------------


"""
import sys
import time
import Adafruit_BBIO.PWM as PWM
from random import randint
from guesser import Guesser
from setter import Setter

import nav_button as Button
import hd44780 as LCD
import ht16k33 as LED

FIRST_TRELLISLED = 0
LAST_TRELLISLED = 15

MIN_PATTERN_LENGTH = 4
MAX_PATTERN_LENGTH = 10
LCD_COL_SPACE = 2
TIMEOUT_CODE = 9998
TIMEOUT = 15.0

END_SCORE = 5

#Constants for the LCD
CURSOR_LEFT_LIMIT = 0
CURSOR_RIGHT_LIMIT = 15
COL_INDEX = 0
ROW_INDEX = 1
ROW_1 = 0
ROW_2 = 1

#pins for lcd
rs = "P1_2"
enable = "P1_4"
d4 = "P2_2"
d5 = "P2_4"
d6 = "P2_6"
d7 = "P2_8"
cols = 16
rows = 2

#testing the code without the hardware
software_debug = False

#Testing individual drivers
button_debug = False
lcd_debug = True
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

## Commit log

2023-02-20 Updated Bill of Materials
2023-03-13 hardware driver for trellis
2023-03-28 added drivers
2023-04-02 cleaned up drivers
2023-05-02 added lbr sch and brd files
    [pattern_game.brd, pattern_game.sch]
2023-05-02 addded other documentation
    [copper_bottom_l4.gbr, copper_inner_l2.gbr, copper_inner_l3.gbr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]
2023-05-02 added pdfs of schematic and board
